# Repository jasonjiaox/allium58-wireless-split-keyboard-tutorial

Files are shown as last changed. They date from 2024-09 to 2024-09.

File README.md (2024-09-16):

# Allium58无线矮轴分体键盘制作过程

本仓库记录从零开始制作一把分体键盘的过程，作为自己制作第一把键盘的记录，也希望能给像我一样刚接触客制化键盘的新人一份参考。

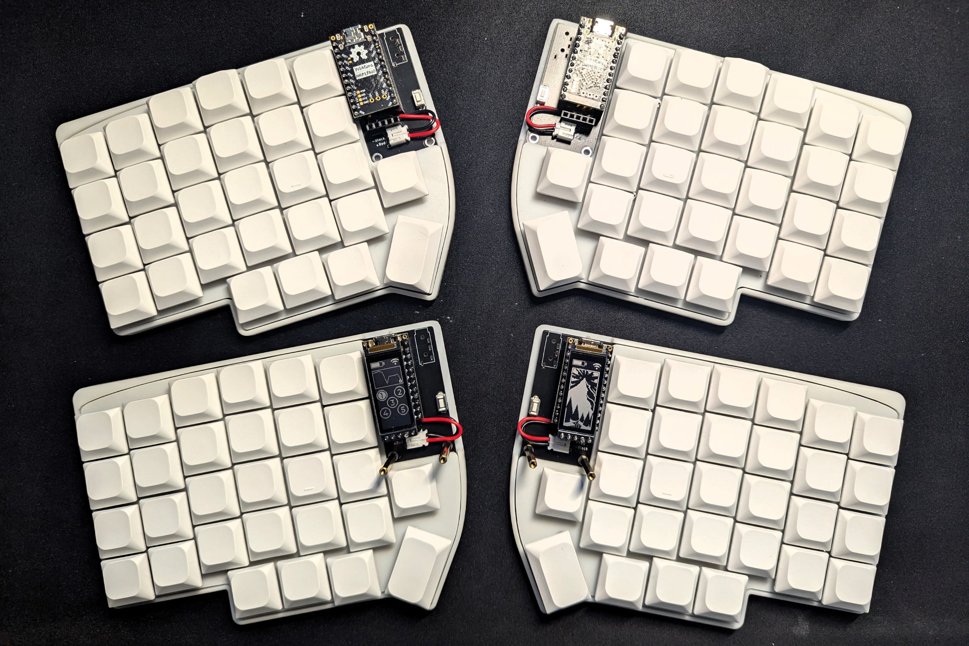
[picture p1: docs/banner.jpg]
Allium58无线矮轴分体键盘


---
## 1. 选择适合的开源项目

每个人对于键盘的需求因人而异，前期可以参考这个仓库[awesome-mechanical-keyboard](https://github.com/Keycapsss/awesome-mechanical-keyboard)来选择适合自己的开源方案，这里也提一下我为什么选择[Allium58](https://github.com/beekeeb/Allium58)：
1. **分体**：选择制作分体键盘的初衷是改善肩膀的疼痛感，实际使用下来也确实做到了这一点，分体键盘可以根据自己的肩宽来放置键盘的位置，有效减少了我的颈部、肩部和腰部的疲劳感
2. **无线**：很多分体键盘是以有线方案为主，比如[dactyl-keyboard](https://github.com/tshort/dactyl-keyboard)，[redox-keyboard](https://github.com/mattdibi/redox-keyboard)，[Lily58](https://github.com/kata0510/Lily58)等，但作为一个无线设备的忠实用户，必然要选择无线优先的方案
3. **矮轴**：正常的机械键盘轴体比较高，需要搭配腕托使用，而矮轴不需要腕托就可以用更自然的手腕姿势来打字，更加的“人体工学”
4. **键位**：有些键盘的键位极为极简，比如3x6配列的[Corne keyboard](https://github.com/foostan/crkbd)，但我个人有很高频的fn，字符等的输入，所以希望键位尽可能的多。

综合以上的要求，我最终选择了[Allium58](https://github.com/beekeeb/Allium58)，一个基于[Lily58](https://github.com/kata0510/Lily58)的6*4+4配列的无线分体键盘方案，相对于Lily58，增强了无线功能，以及增加了对矮轴键盘的兼容性。

# 物料清单

[Allium58](https://github.com/beekeeb/Allium58)的README有列出制作键盘所需的BOM，但是有些物料的具体型号参数并没有详细表明，实际采购的时候踩了一些坑，我这里把BOM更详细的列出，希望能有帮助：

| 名称 | 数量 | 备注 |
|:---|:---|:---|
| PCB | 1套 | |
| 外壳 | 1套  | 可以3D打印 |
| 屏幕保护 | 2 | 亚克力 |
| Promicro NRF52840或者nice!nano | 2 | |
| 复位开关 | 2 | 两脚 3*6*4.3MM 微动开关/轻触开关 |
| 二极管 | 58 | 贴片 1N4148W 1206/SOD-123 丝印T4 150MA 75V开关二极管 |
| 矮轴热插拔轴座 | 58 | 佳达隆矮轴热插拔轴座GATERON |
| 矮轴 | 58 | Gateron佳达隆矮轴2.0 |
| 键帽 | 58 | 1u 56个, 1.5u 2个 [GLP Keycaps对比](https://showcase.beekeeb.com/the-keycaps-of-gateron-low-profile-key-switches-and-kailh-choc-v1-key-switch/) |
| 双通六角铜柱螺母柱M2 5mm | 10 | 用于外壳组装 |
| 双通六角铜柱螺母柱M2 9mm | 4  | 用于屏幕保护 |
| 304不锈钢沉头机丝十字加长平头螺丝 M2 4mm | 28 | |
| 贴片拨动开关 | 2 | |
| PH2.0弯针插座接插件 | 2 | |

---
# PCB
PCB推荐到嘉立创进行打印，对比过几家的价格，嘉立创是最便宜的，PCB打印最低5片，总共价格是128元左右。Allium的仓库中有使用KiCad制作的PCB工程文件，但是要注意的是，国内的打印PCB是不支持提供KiCad的工程文件，需要自己转成Gerber文件，这里推荐使用KiCad中的嘉立创扩展插件来转换成对应的Gerber文件，如果想偷懒可以直接使用我已经生成好的两个[Gerber文件](./pcb)。
然后在嘉立创下单中心中提交转换好的两个Gerber文件（左侧和右侧各一个Gerber的zip压缩包），板子数量选择5，其他使用默认即可，不过阻焊层我个人喜欢黑色的，这就因人而异了。在右侧可以实时看到PCB的3D效果图，确保文件没有问题。另外，推荐下单的时候跟客服说在生产前要确认下生产稿，尽可能做到万无一失。

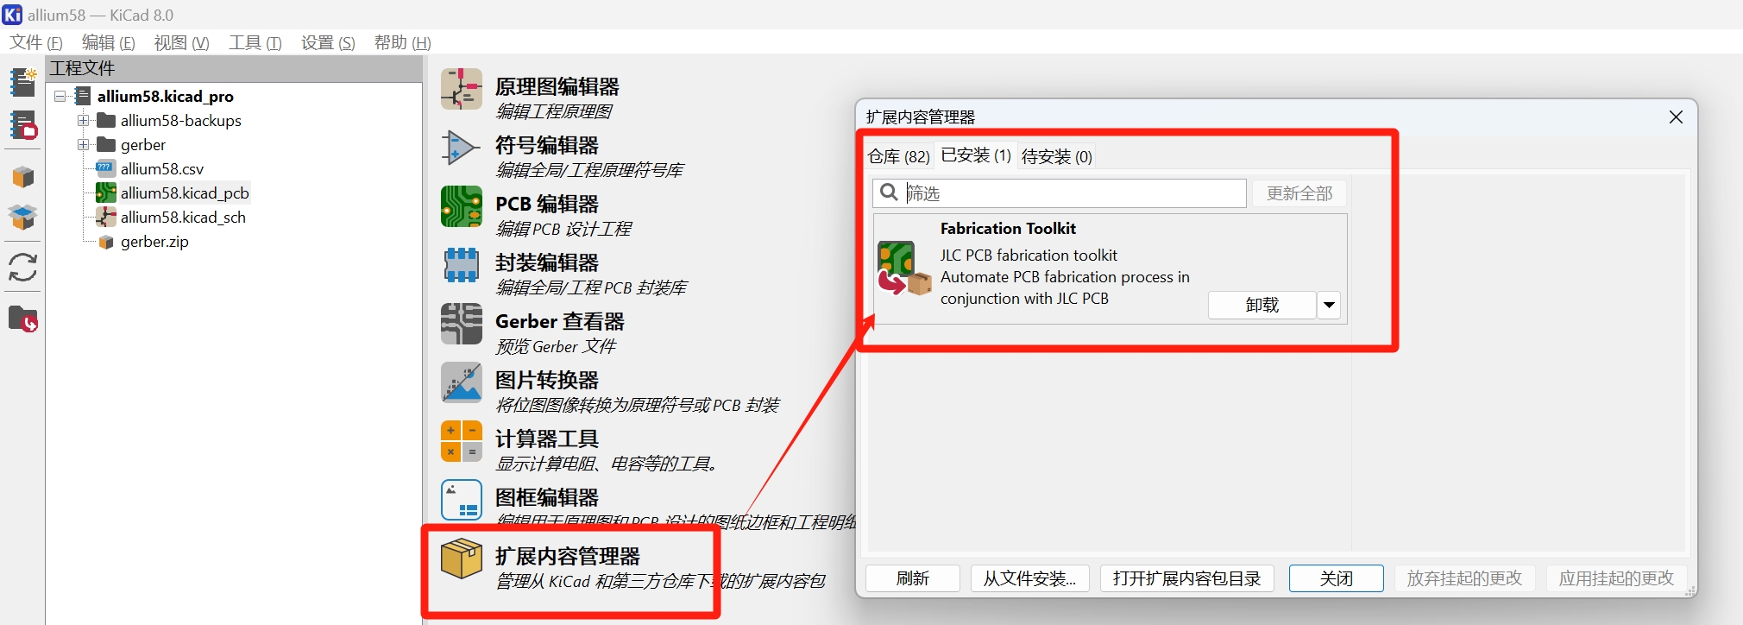
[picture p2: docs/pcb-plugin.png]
嘉立创拓展程序1


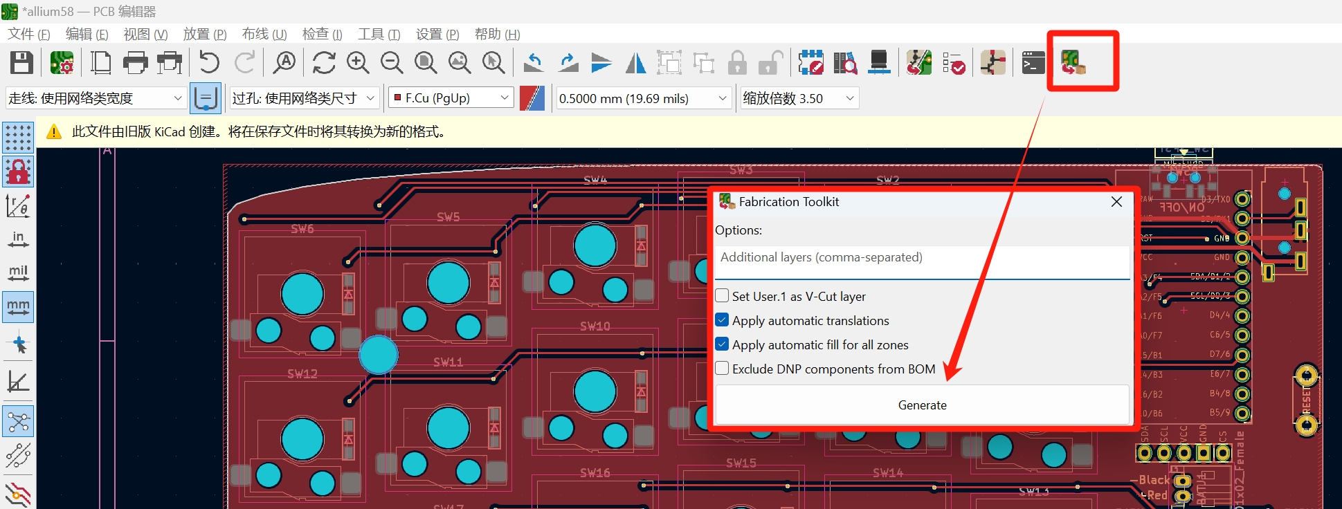
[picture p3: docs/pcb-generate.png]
嘉立创拓展程序2


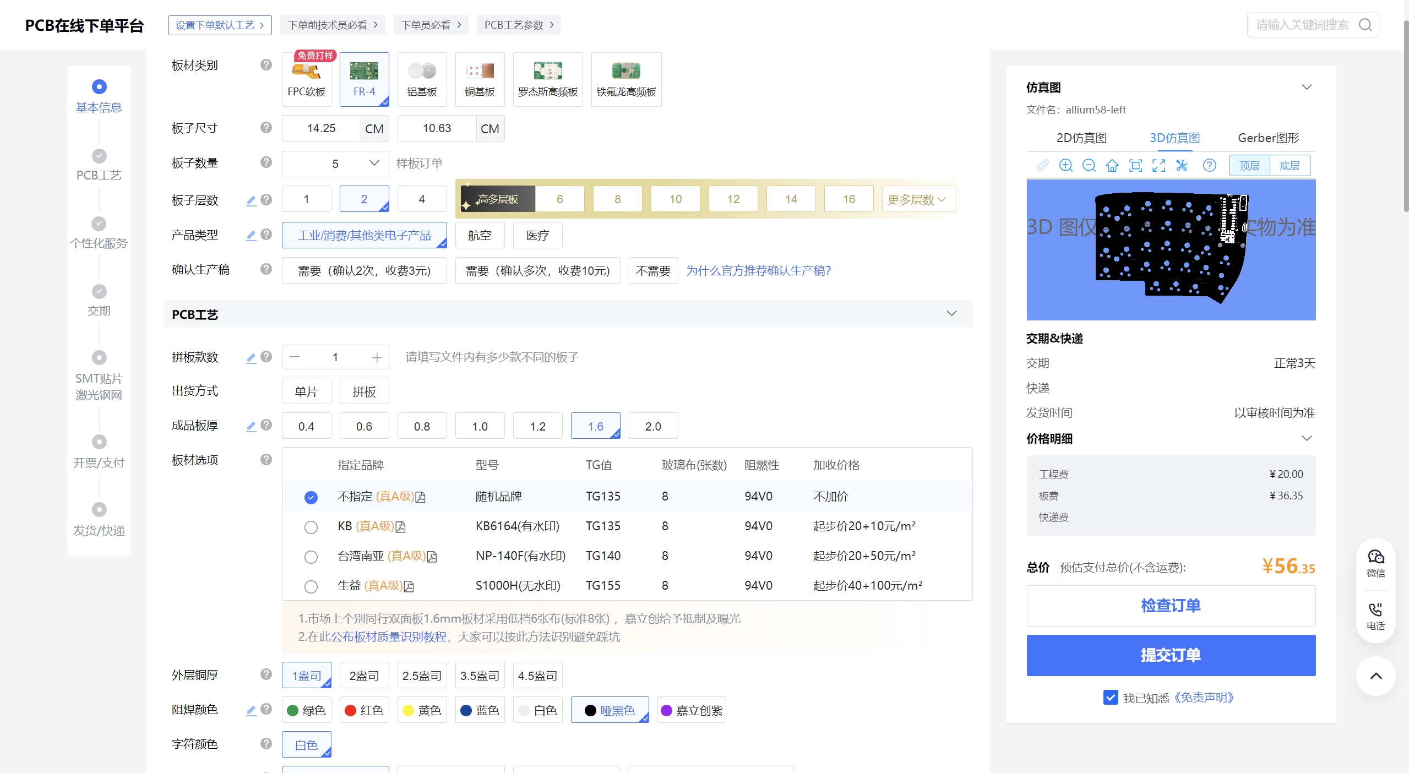
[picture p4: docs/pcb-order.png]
嘉立创拓展程序3


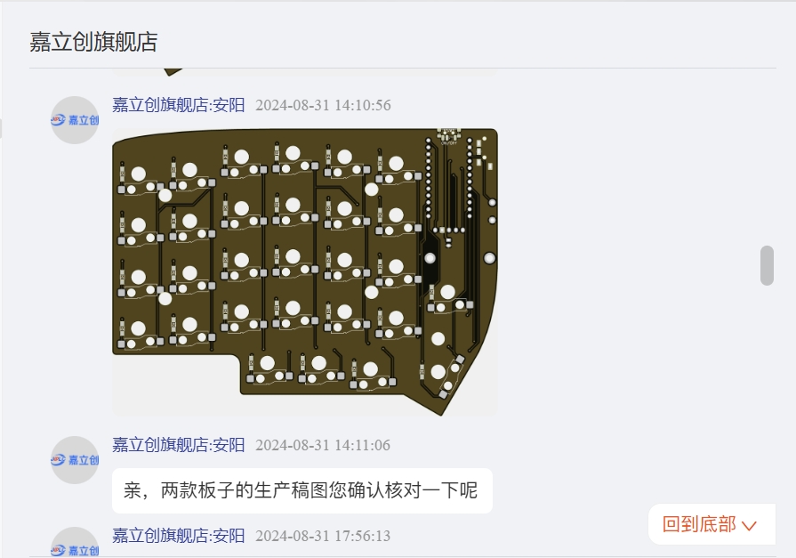
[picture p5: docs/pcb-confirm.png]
嘉立创拓展程序4


---
## 外壳
外壳的3d打印文件可以在[这里找到](https://www.printables.com/model/657755-low-profile-case-for-allium58-glp)，要注意的是里面只提供了左右其中一侧的3d打印文件，在找商家下单的时候一定要强调要给3d打印文件做一份镜像，这样才能是完整的左右各一个的整套外壳。材料推荐使用树脂，颜色可以选择白色和黑色，一套的白色价格大概50，黑色80，如果打印的数量多，比如我打印了三套白色的，价格是122，如果是黑色的价格是200元。
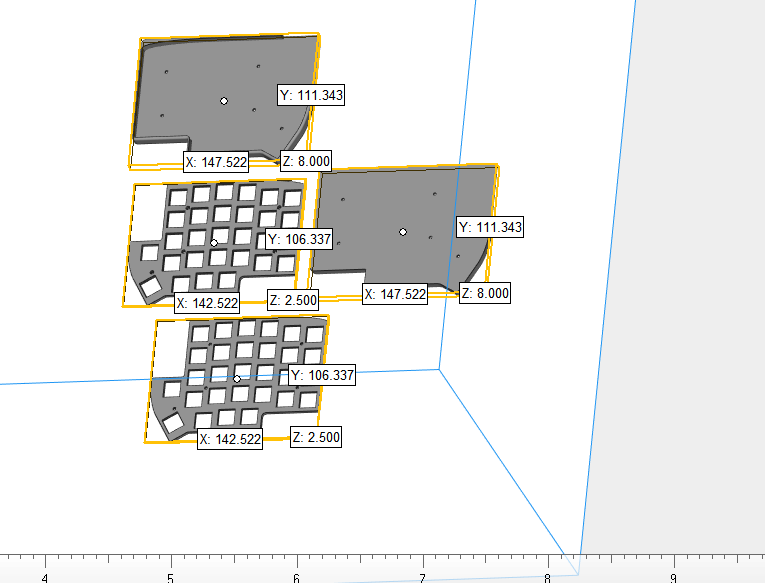
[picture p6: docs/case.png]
3d打印外壳


---
## 焊接&组装
焊接是整个制作中最重要的过程，推荐要有一台万用表来进行测试焊接效果。焊接时优先焊接贴片元件，比如二极管，复位开关，拨动开关等，其次是热插拔轴座，最后是排针插座。

焊接贴片元件前，可以先在焊盘的一侧上满锡，然后焊接好元件的一侧后，再焊接另一侧，此方法适用于二极管和热插拔插座：

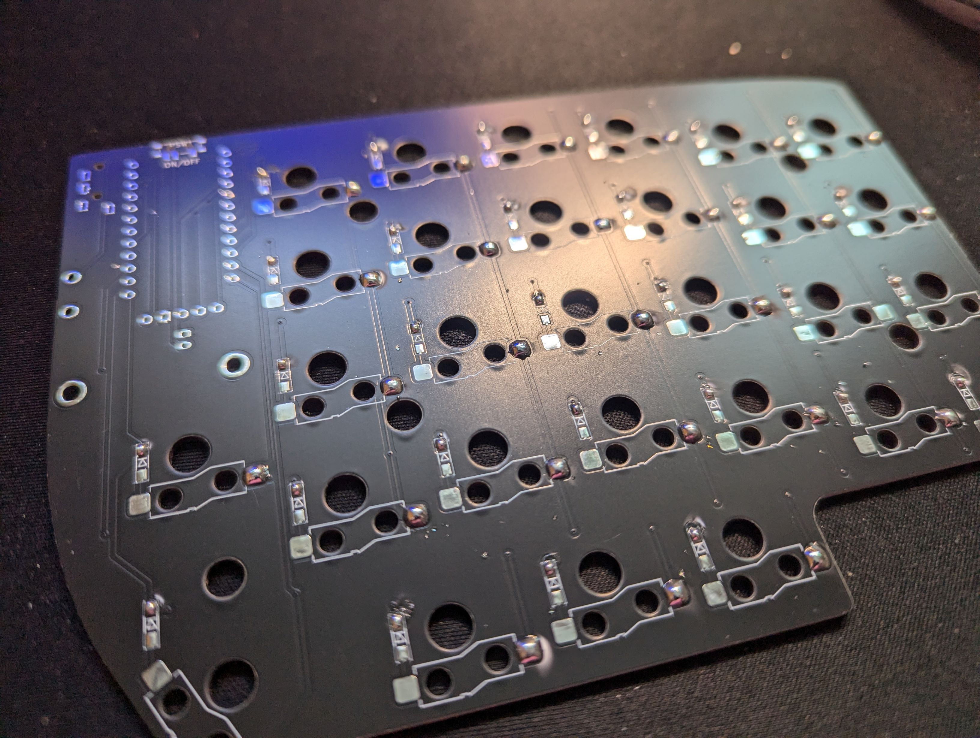
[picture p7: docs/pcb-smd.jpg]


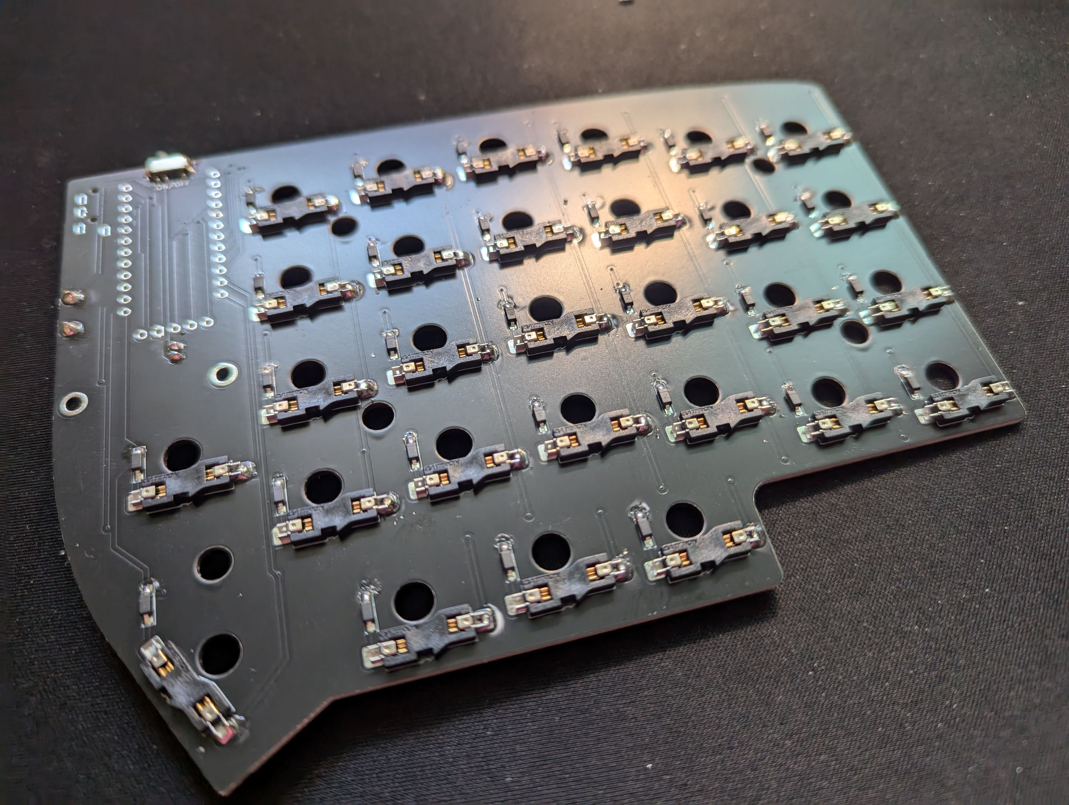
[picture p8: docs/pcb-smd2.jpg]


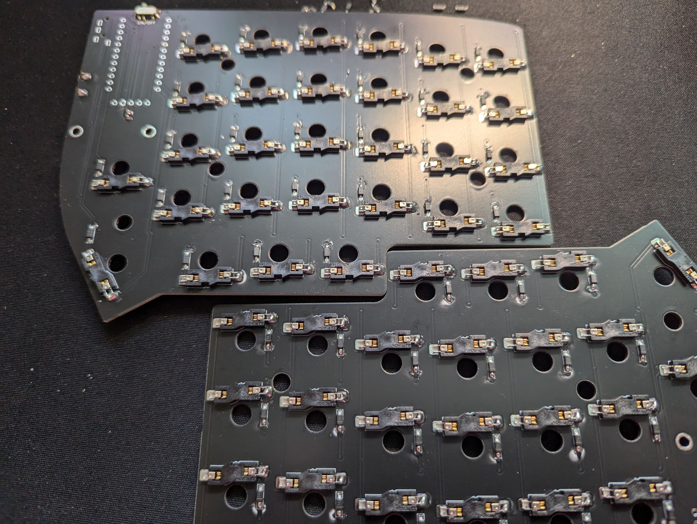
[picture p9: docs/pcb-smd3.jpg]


焊接的时候一定要仔细检查有没有虚焊的情况，比如下图标注的二极管的正极就有虚焊，在实际测试中这个按键不灵：
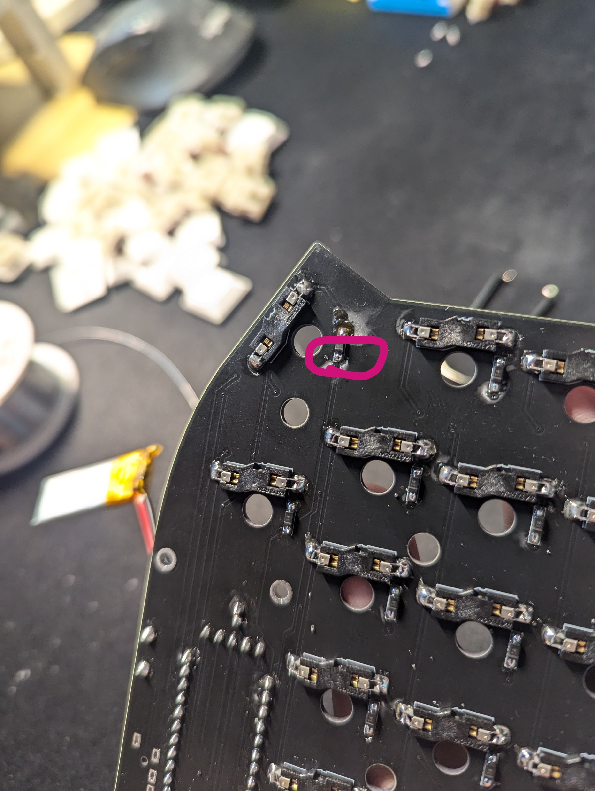
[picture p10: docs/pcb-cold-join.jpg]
虚焊


所有元件都焊接好以后，不建议直接就安装外壳，然后再安装轴体和键帽，因为一旦有按键不正常，就需要全部拆下来重新排查，我建议可以先在不安装外壳的情况下，先把轴体安装在pcb上，然后烧录固件，连接电脑测试一下各个按键的效果，这里建议使用一些[Keyboard Tester](https://www.keyboardtester.com/tester.html)来测试各个按键的效果：

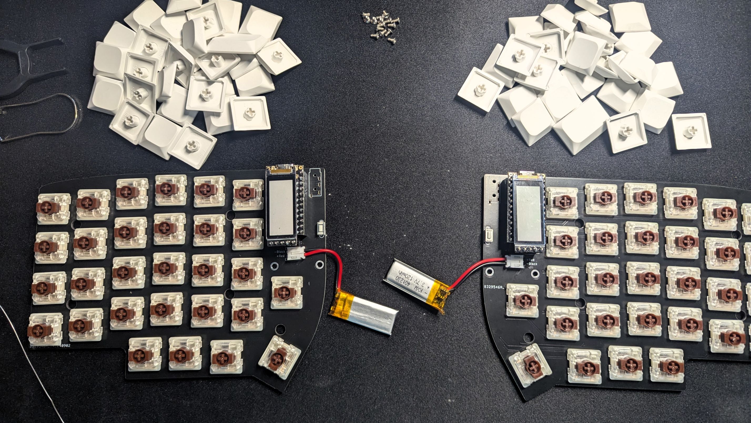
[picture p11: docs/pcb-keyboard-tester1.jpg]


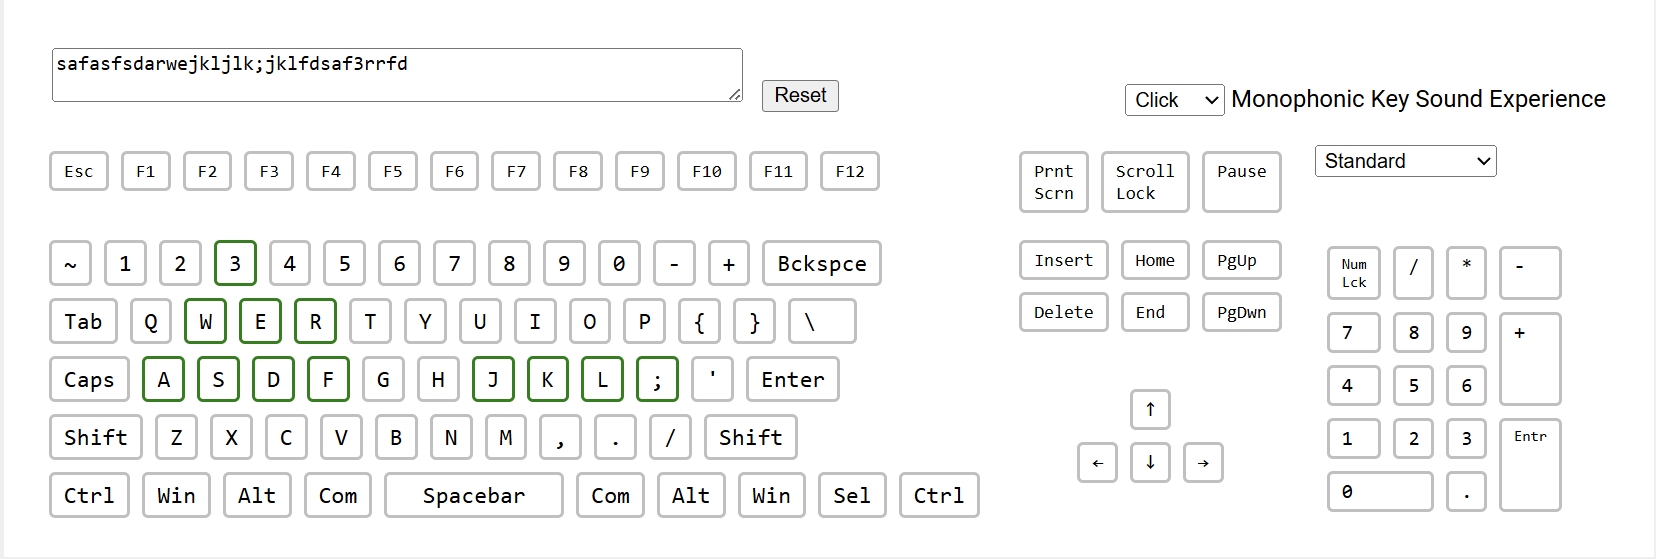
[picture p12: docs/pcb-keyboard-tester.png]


---
## 固件烧录

键盘固件使用的是[ZMK Firmware](https://zmk.dev/)，相比于QMK等固件方案，ZMK原生支持蓝牙连接，可以实现真正的无线键盘体验。而且ZMK已经包含了Lily58的预配置文件，再配合可视化配置ZMK按键映射的开源项目：[keymap-editor](https://github.com/nickcoutsos/keymap-editor)，可以非常容易的配置适合自己的按键方案。这里也放出我的按键方案，因为我是一个vim用户，按键也更倾向于适用vim的使用习惯：[allium58-zmk-config](https://github.com/jasonjiaox/allium58-zmk-config)。
这里只强调一个配置项，因为我做了两把键盘，因此需要对设备名称做一下区分，可以使用：`CONFIG_ZMK_KEYBOARD_NAME="device name"`来区分设备。

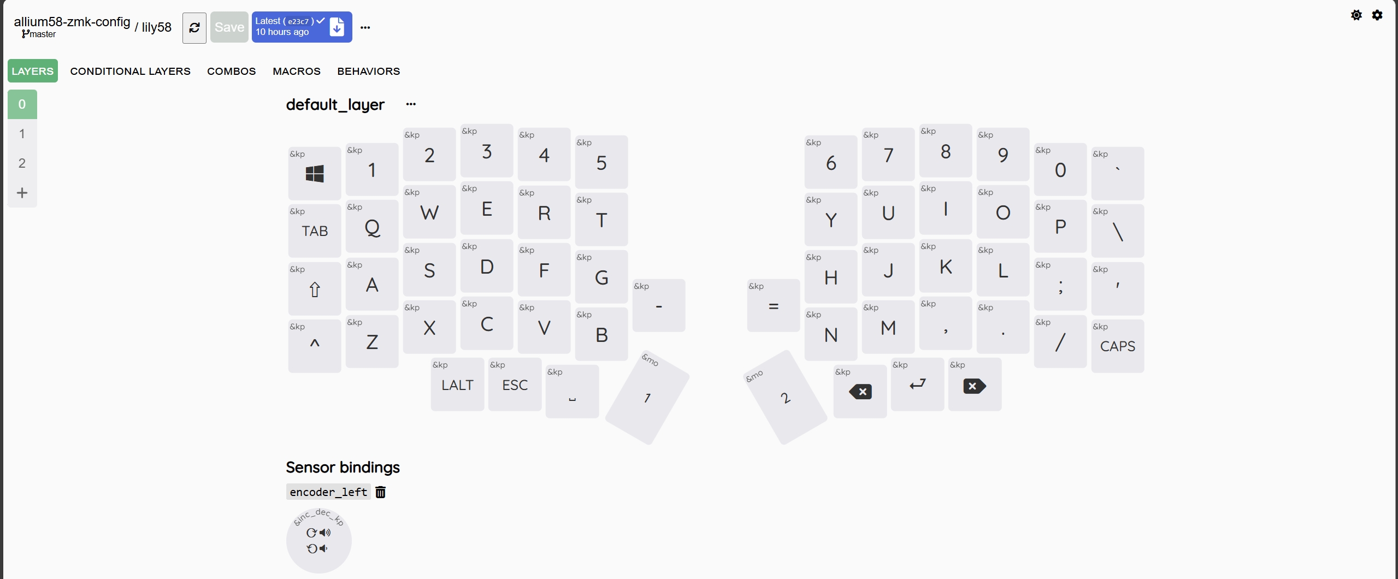
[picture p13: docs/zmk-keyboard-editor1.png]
按键映射


---
## 打字测试

烧录好固件后，按照一个常规的蓝牙键盘的连接方法去连接键盘即可，第一次上手分体键盘肯定要有一个适应的过程，毕竟键盘布局跟传统的键盘有了很大的差别，这里建议使用一些打字软件来熟悉一下键位，比如[monkeytype](https://monkeytype.com/)，你也可以在这里看到我的打字测试视频：https://www.youtube.com/watch?v=naZ9xbLBMjA

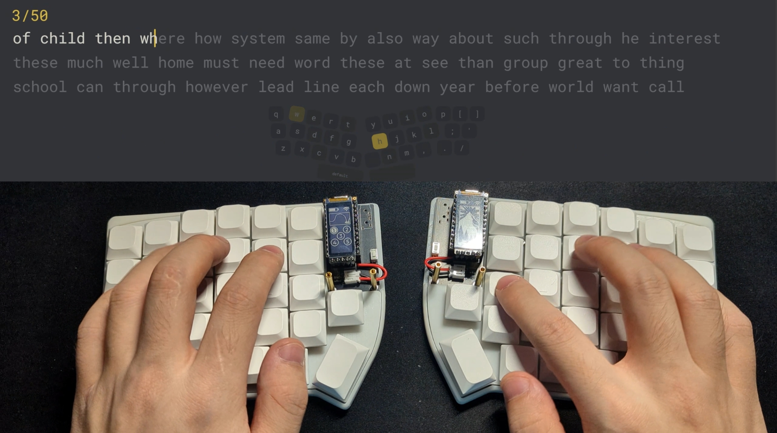
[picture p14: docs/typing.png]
打字测试


---
## 最后
从决定做一把无线分体键盘，调研各个开源项目，到最后做出成品总共花费了我大概两周的时间，然后又花了一周的时间才慢慢熟悉键位，学习成本有点类似刚上手vim一样的陡峭，但是一旦熟悉了之后，整个打字体验跟之前有了质的提升。最重要的是用了分体键盘，我能够把我的肩膀打开，身体也会自然的向座椅上靠，而不是之前身体不自觉的前倾而导致的颈椎和肩部的疼痛感。
这把分体键盘实实在在的改善了我的打字体验和健康状况，也希望当你拥有一把分体键盘的时候，也能感受到自己制作一把键盘的快乐以及人体工学的舒适，祝好~

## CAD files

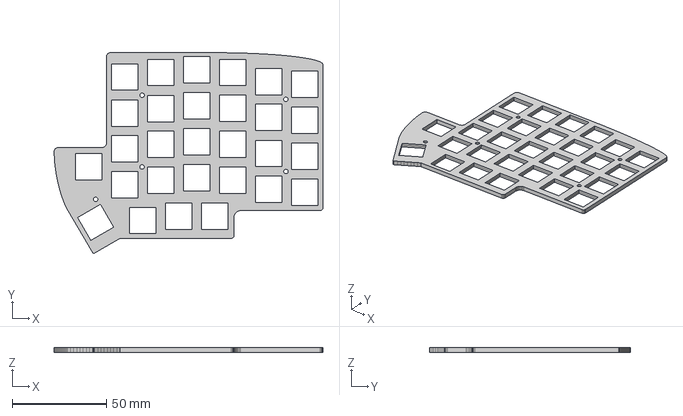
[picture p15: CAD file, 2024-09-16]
case/allium58-top-switch-plate.step
142.5 x 106.3 x 2.50 mm

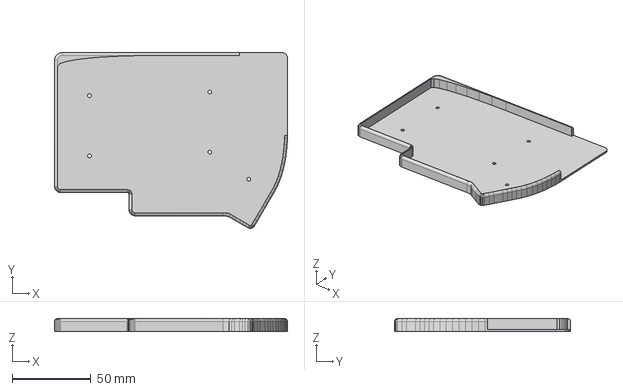
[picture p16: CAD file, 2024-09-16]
case/allium58-bottom-case.step
147.5 x 111.3 x 8.00 mm

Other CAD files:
case/allium58-bottom-case.stl
case/allium58-top-switch-plate.stl

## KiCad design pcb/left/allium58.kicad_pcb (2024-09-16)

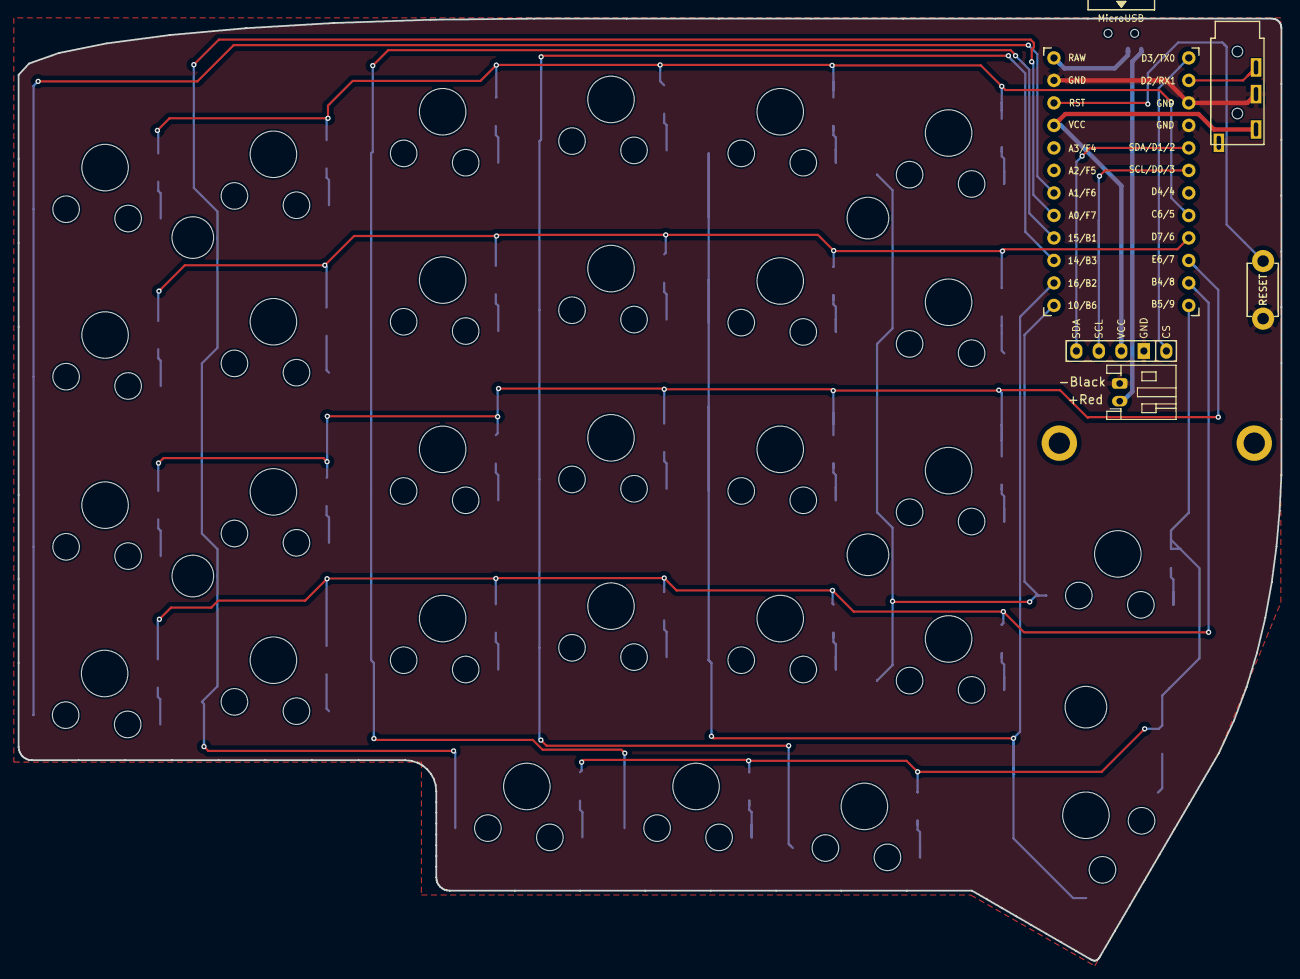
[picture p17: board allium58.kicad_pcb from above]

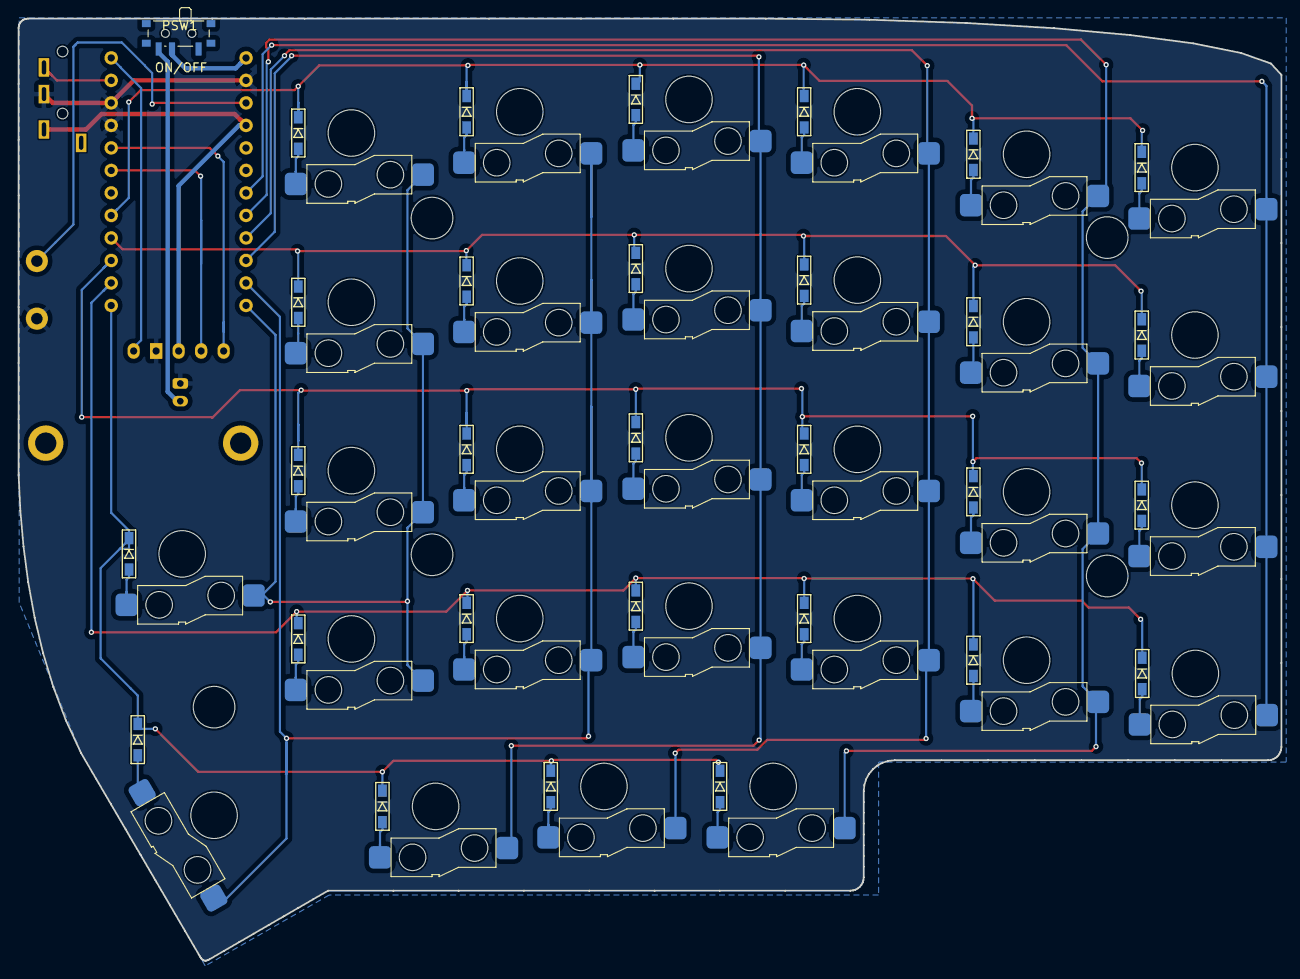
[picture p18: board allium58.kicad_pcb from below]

Board: 2 copper layers, 142.5 x 106.3 mm, 71 parts (37 on the bottom side), 49 nets.

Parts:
BATJ1: Conn_01x02_Female; JST_PH_S2B-PH-K_1x02_P2.00mm_Horizontal
D1, D2, D3, D4, D5, D6, D7, D8, D9, D10, D11, D12, D13, D14, D15, D16, D17, D18, D19, D20, D21, D22, D23, D24, D25, D26, D27, D28, D29: D; D3_SMD_v2
J2: 4PIN; MJ-4PP-9
J3: OLED; nice_view_1side
PSW1: SW_SPST; SW_SPDT_PCM12
RSW1: SW_RST; TACT_SWITCH_TVBP06
SW1, SW2, SW3, SW4, SW5, SW6, SW7, SW8, SW9, SW10, SW11, SW12, SW13, SW14, SW15, SW16, SW17, SW18, SW19, SW20, SW21, SW22, SW23, SW24, SW25, SW26, SW27, SW28, SW29: SW_PUSH; SW_Gateron_LowProfile_HotSwap
TH1, TH2: HOLE; M2_HOLE_PCB
TH3, TH4, TH5, TH6, TH7: HOLE; HOLE_M2_TH
U1: ProMicro; ProMicro_v3

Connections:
+BATT: BATJ1.1, PSW1.3 (C)
CS: J3.5, U1.1 (TX(PD3))
DATA: J2.3, U1.2 (RX(PD2))
GND: BATJ1.2, J2.2, J3.4, RSW1.1, U1.3 (GND), U1.4 (GND), U1.23 (GND)
unnamed: D1.2 (A), SW1.2
unnamed: D2.2 (A), SW2.2
unnamed: D3.2 (A), SW3.2
unnamed: D4.2 (A), SW4.2
unnamed: D5.2 (A), SW5.2
unnamed: D6.2 (A), SW6.2
unnamed: D7.2 (A), SW7.2
unnamed: D8.2 (A), SW8.2
unnamed: D9.2 (A), SW9.2
unnamed: D10.2 (A), SW10.2
unnamed: D11.2 (A), SW11.2
unnamed: D12.2 (A), SW12.2
unnamed: D13.2 (A), SW13.2
unnamed: D14.2 (A), SW14.2
unnamed: D15.2 (A), SW15.2
unnamed: D16.2 (A), SW16.2
unnamed: D17.2 (A), SW17.2
unnamed: D18.2 (A), SW18.2
unnamed: D19.2 (A), SW19.2
unnamed: D20.2 (A), SW20.2
unnamed: D21.2 (A), SW21.2
unnamed: D22.2 (A), SW22.2
unnamed: D23.2 (A), SW23.2
unnamed: D24.2 (A), SW24.2
unnamed: D25.2 (A), SW25.2
unnamed: D26.2 (A), SW26.2
unnamed: D27.2 (A), SW27.2
unnamed: D28.2 (A), SW28.2
unnamed: D29.2 (A), SW29.2
RESET: RSW1.2, U1.22 (RST)
SCL: J3.2, U1.6 (SCL(PD0))
SDA: J3.1, U1.5 (SDA(PD1))
VCC: J2.1, J3.3, U1.21 (VCC)
col0: SW6.1, SW12.1, SW18.1, SW24.1, U1.18 (A1(PF6))
col1: SW5.1, SW11.1, SW17.1, SW23.1, SW29.1, U1.17 (A0(PF7))
col2: SW4.1, SW10.1, SW16.1, SW22.1, SW28.1, U1.16 (D15(PB1))
col3: SW3.1, SW9.1, SW15.1, SW21.1, SW27.1, U1.15 (D14(PB3))
col4: SW2.1, SW8.1, SW14.1, SW20.1, SW26.1, U1.14 (D16(PB2))
col5: SW1.1, SW7.1, SW13.1, SW19.1, SW25.1, U1.13 (D10(PB6))
raw: PSW1.2 (B), U1.24 (RAW)
row0: D1.1 (K), D2.1 (K), D3.1 (K), D4.1 (K), D5.1 (K), D6.1 (K), U1.8 (D5(PC6))
row1: D7.1 (K), D8.1 (K), D9.1 (K), D10.1 (K), D11.1 (K), D12.1 (K), U1.9 (D6(PD7))
row2: D13.1 (K), D14.1 (K), D15.1 (K), D16.1 (K), D17.1 (K), D18.1 (K), U1.10 (D7(PE6))
row3: D19.1 (K), D20.1 (K), D21.1 (K), D22.1 (K), D23.1 (K), D24.1 (K), U1.11 (D8(PB4))
row4: D25.1 (K), D26.1 (K), D27.1 (K), D28.1 (K), D29.1 (K), U1.12 (D9(PB5))
